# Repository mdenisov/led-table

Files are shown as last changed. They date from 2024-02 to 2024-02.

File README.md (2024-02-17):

Flexible modular system. The modules are connected to each other to form a single network. Each module works independently of the others.

The entire system consists of a basic control module with **ESP8266** and an endless set of sensor modules.

The number of modules is limited only by the power of the power supply.

On the base module you can set the color and brightness of the diodes.

## Build
The hexagon parts always have the same distance to each other, use spacers to insert. Also use hexagon spacers to tightly fill the perimeter

The hexagons are printed in two colors. The top in Black and the rest in Clear.

## PCB
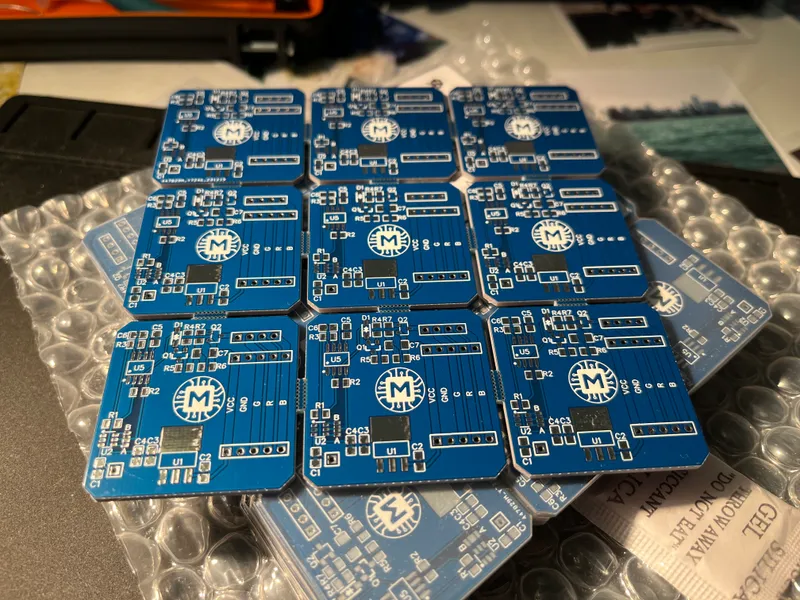
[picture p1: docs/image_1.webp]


Solder pin A for a low signal when sensor triggered. **C1** capacitor serves to reduce the sensitivity of the sensor. I didn't solder it.

You can adjust the glow time and smoothness of the diodes.
All this can be configured on the sensor board by replacing elements **C6**, **R3**, **R5**, **R6**.

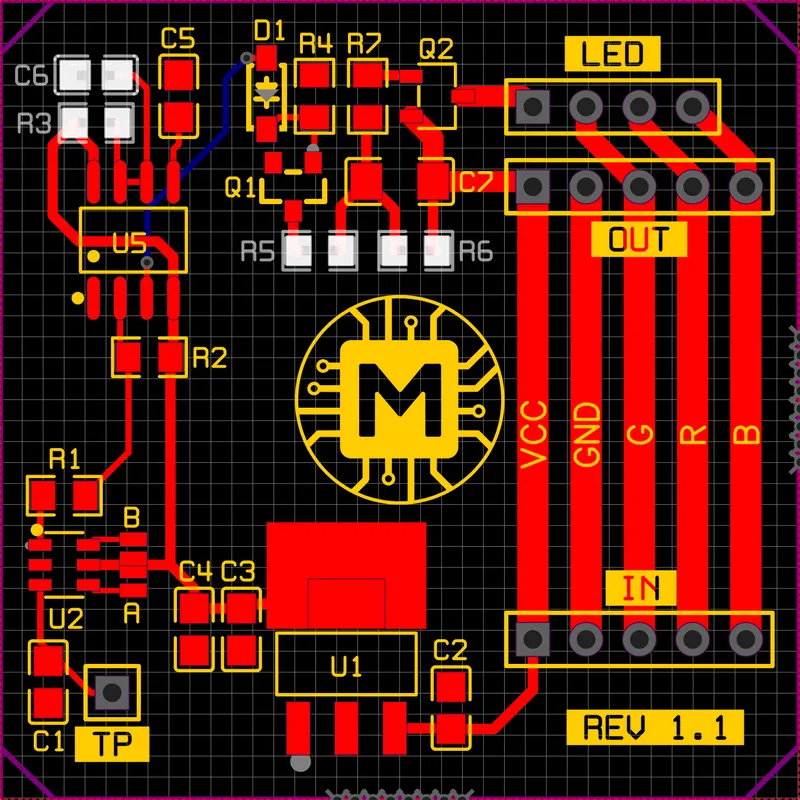
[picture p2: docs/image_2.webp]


- **C6**, **R3** are responsible for the glow time of the diodes and is calculated by the formula t=C6xR3x1.1 (in my case ~1s);
- **R5** is responsible for fade-in of the diodes;
- **R6** is responsible for fade-out of the diodes;

## Assembly
For the sensor to work, it is necessary to make a ring of copper wire, I use 2.5 mm2. For even winding, use a round tower. Solder the ring to the **TP** pin with wire. 

Cut 15cm of LED strip (3 sections) and solder the contacts with wire into a ring. Solder wires to these contacts for further connection to the sensor board.

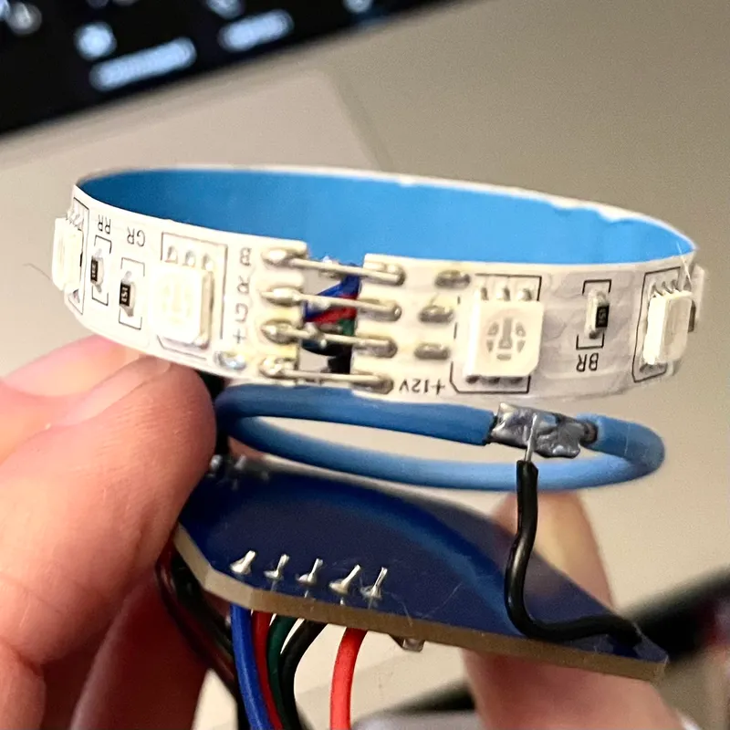
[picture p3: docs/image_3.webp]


You can connect the LED strip both from the inside and from the outside, make sure that the wires are as far away from the touch ring as possible.

Place everything in its place in the hexagon.

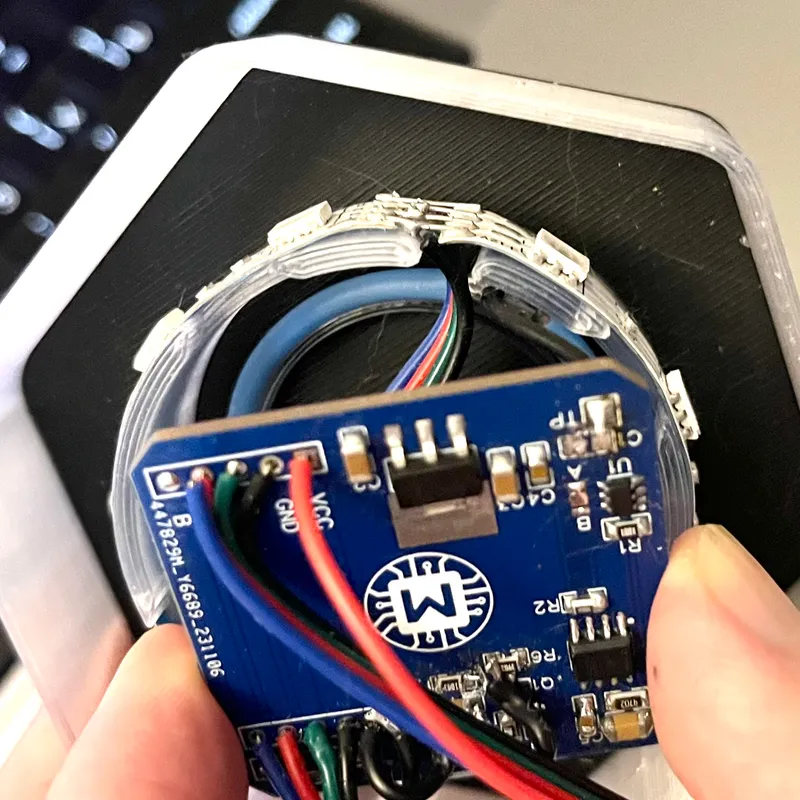
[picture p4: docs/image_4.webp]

pcb
pcb

The sensor module is ready.

The modules are connected sequentially one after another into a single network using JST connectors for quick replacement or hard soldered with wires.

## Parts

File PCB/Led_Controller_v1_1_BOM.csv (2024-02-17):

ID | Name | Designator | Footprint | Quantity | Manufacturer Part | Manufacturer | Supplier | Supplier Part
1 | 10u | C1 | C0805 | 1
2 | 100n | C2,C7 | C0805 | 2
3 | 10n | C3 | C0805 | 1
4 | 3.9n | C4 | C0805 | 1
5 | 22u | C5,C6 | C0805 | 2
6 | 1N4148 | D1,D2,D4 | SOD-123_L2.7-W1.6-LS3.7-RD-1 | 3 | 1N4148 | STMicroelectronics | LCSC | C13769
7 | MBR0530T3G | D3,D5 | SOD-123_L2.7-W1.6-LS3.7-RD-1 | 2 | MBR0530T3G | onsemi(安森美) | LCSC | C236079
8 | HDR-F-2.54_1x5 | H1 | HDR-F-2.54_1X5 | 1 |  |  | LCSC | C50950
9 | 10uH | L1 | IND-SMD_L7.0-W6.6_FXL0630 | 1 | FXL0624-150-M | cjiang(长江微电) | LCSC | C524609
10 | IRLML2502 | Q1,Q2,Q3 | SOT-23_L2.9-W1.3-P1.90-LS2.4-BR | 3 | IRLML2502 | UMW(广东友台半导体) | LCSC | C347503
11 | 10k | R1,R2,R3,R4,R6,R7,R9,R13 | R0805 | 8
12 | 100R | R5,R8,R11 | R0805 | 3
13 | 100k | R10 | R0805 | 1
14 | 47k | R12 | R0805 | 1
15 | 18k | R14 | R0805 | 1
16 | 6.8k | R15 | R0805 | 1
17 | 2.4GHz | U1 | WIFIM-SMD_ESP-12F-ESP8266MOD | 1 | ESP-12F(ESP8266MOD) | Ai-Thinker(安信可) | LCSC | C82891
18 | UART | U2 | UART | 1
19 | VCC | U3 | CONN-TH_P2.54_KF128-2.54-2P | 1 | KF128-2.54-2P | KEFA(科发) | LCSC | C474920
20 | MP2307DN-LF-Z | U4 | SOP-8_L4.9-W3.9-P1.27-LS6.0-BL-EP | 1 | MP2307DN-LF-Z | MPS | LCSC | C18921

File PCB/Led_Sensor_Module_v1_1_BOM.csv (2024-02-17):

ID | Name | Designator | Footprint | Quantity | Manufacturer Part | Manufacturer | Supplier | Supplier Part
1 | 22u | C2,C3,C6 | C0805 | 3
2 | 100n | C4 | C0805 | 1
3 | 10n | C5 | C0805 | 1
4 | 10u | C7 | C1206 | 1
5 | 1N4148 | D1 | SOD-123_L2.7-W1.6-LS3.7-RD-1 | 1 | 1N4148 | STMicroelectronics | LCSC | C13769
6 | HDR-F-2.54_1x5 | H1,H2 | HDR-F-2.54_1X5 | 2 |  |  | LCSC | C50950
7 | LED | H3 | HDR-F-2.54_1X4 | 1 |  |  | LCSC | C225501
8 | TP | J1 | HDR-M-2.54_1X1 | 1 |  |  | LCSC | C81276
9 | IRLML2502 | Q1 | SOT-23_L2.9-W1.3-P1.90-LS2.4-BR | 1 | IRLML2502 | UMW(广东友台半导体) | LCSC | C347503
10 | IRLML2244 | Q2 | SOT-23-3_L2.9-W1.6-P1.90-LS2.8-BR | 1 |  | VBsemi(微碧) | LCSC | C558172
11 | 1k | R1 | R0805 | 1
12 | 10k | R2,R4,R7 | R0805 | 3
13 | 47k | R3 | R0805 | 1
14 | 390k | R5 | R0805 | 1
15 | 100k | R6 | R0805 | 1
16 | AMS1117 | U1 | SOT-223-3_L6.4-W3.5-P2.30-LS7.0-BR | 1 | AMS1117-3.3 | 国芯佳品 | LCSC | C2992570
17 | TTP223-BA6 | U2 | SOT-23-6_L2.9-W1.6-P0.95-LS2.8-BL | 1 | TTP223-BA6 | null | LCSC | C80757
18 | B | U3 | PAD-JUMPER-2-NO_NO_SILK | 1
19 | A | U4 | PAD-JUMPER-2-NO_NO_SILK | 1
20 | NE555 | U5 | SOIC-8_L4.9-W3.9-P1.27-LS6.0-BL | 1 | NE555 | IDCHIP(英锐芯) | LCSC | C5125085

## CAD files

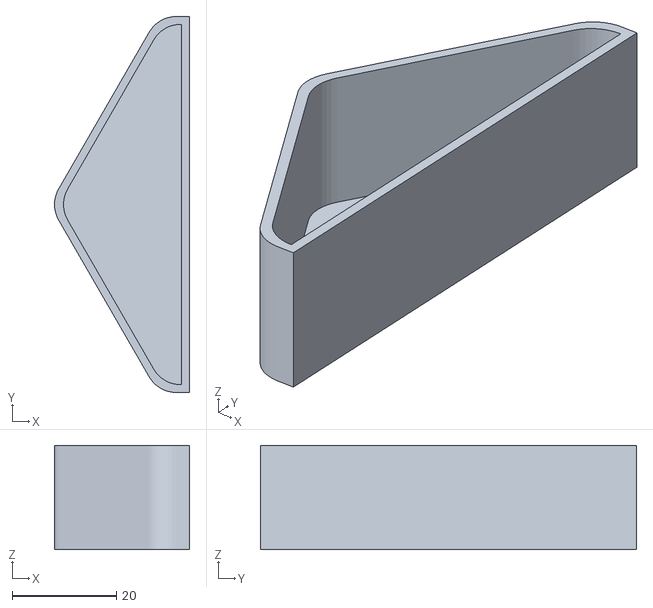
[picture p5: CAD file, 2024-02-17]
STL/Filling_2.stl
25.9 x 72.0 x 20.0

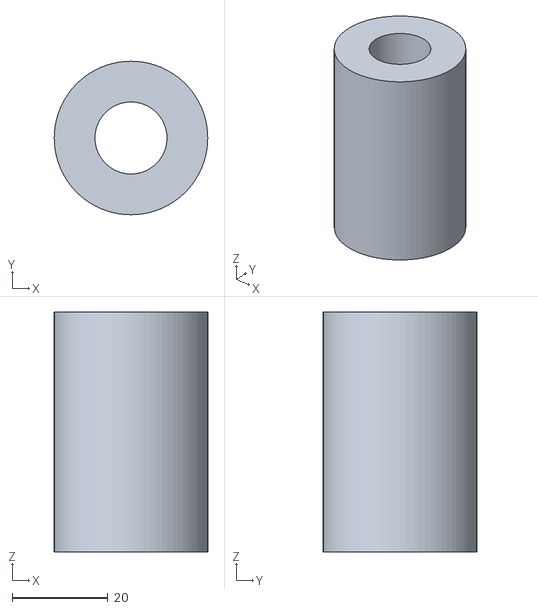
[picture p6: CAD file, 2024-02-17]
STL/Tower.stl
32.0 x 32.0 x 50.0

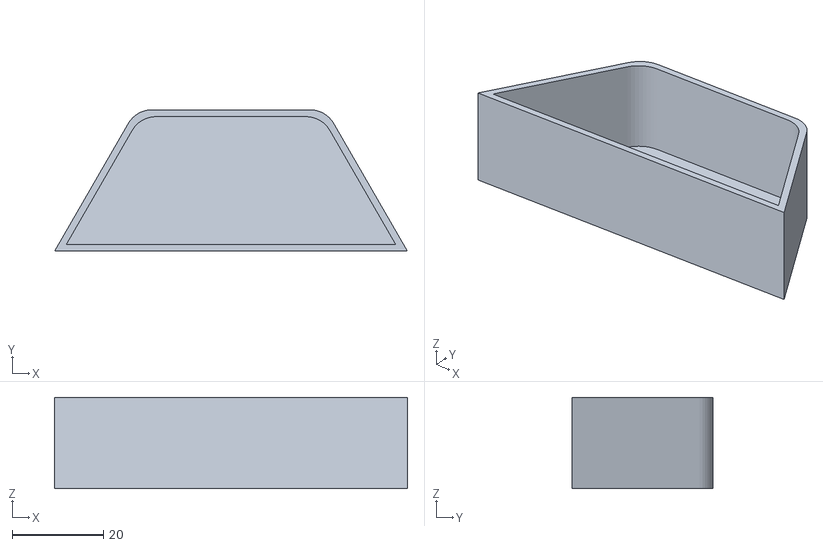
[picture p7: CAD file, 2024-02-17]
STL/Filling_1.stl
77.4 x 31.0 x 20.0

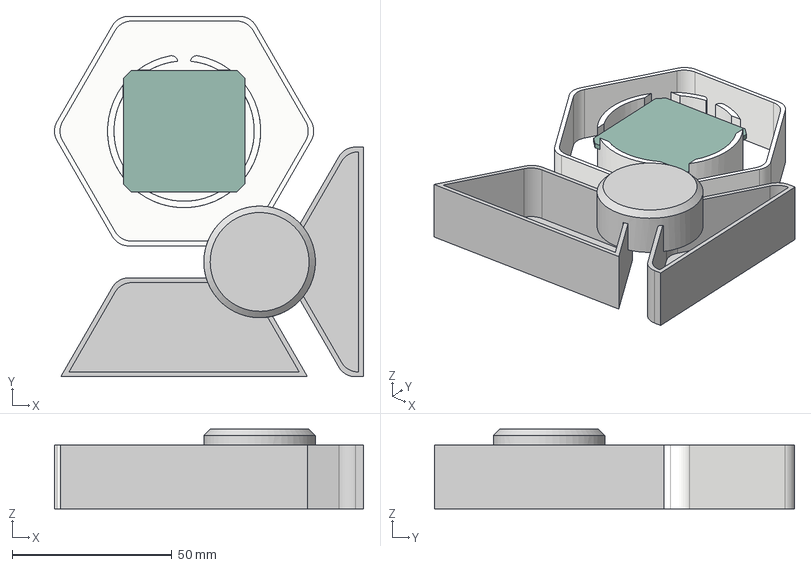
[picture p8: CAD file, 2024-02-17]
STL/Hexagon led table.step
96.9 x 113.0 x 25.0 mm
Base
Filling_1
Filling_2
Spacer
PCB

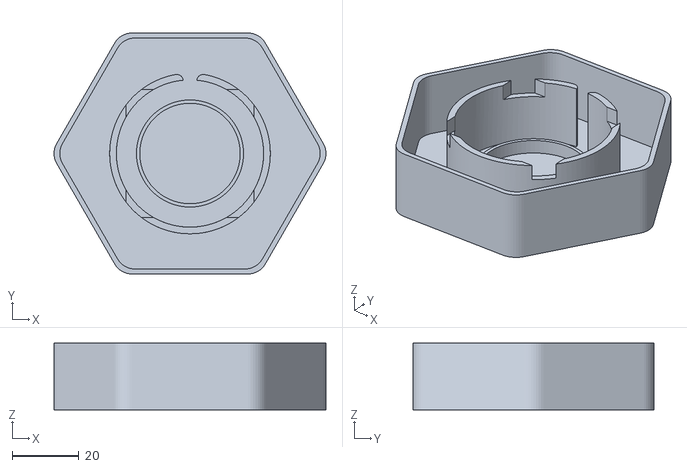
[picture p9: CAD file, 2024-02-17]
STL/Base.stl
81.3 x 72.0 x 20.0

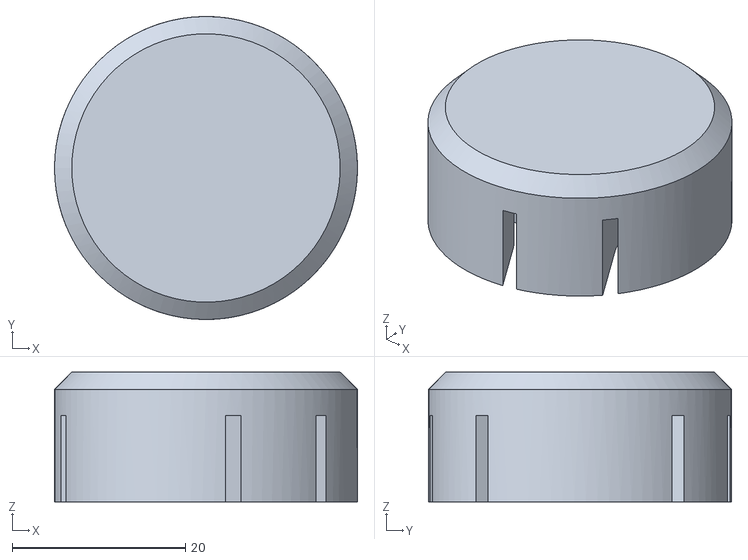
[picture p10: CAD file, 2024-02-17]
STL/Spacer.stl
35.0 x 35.0 x 15.0

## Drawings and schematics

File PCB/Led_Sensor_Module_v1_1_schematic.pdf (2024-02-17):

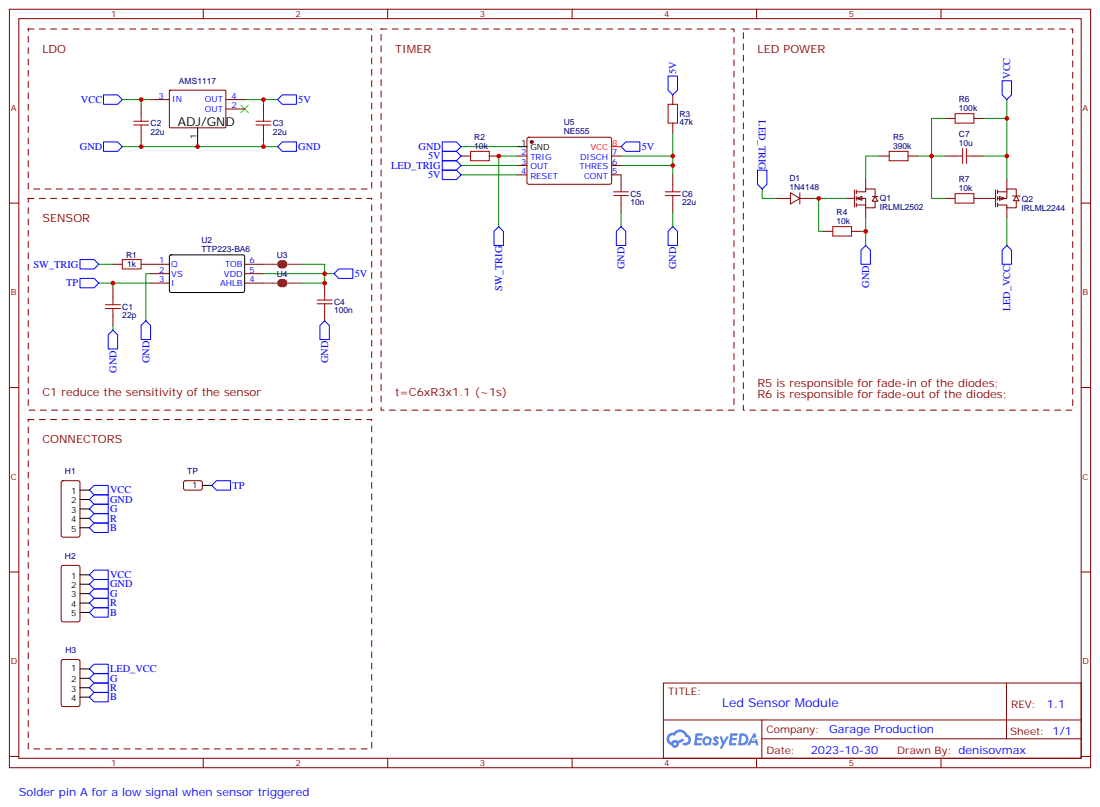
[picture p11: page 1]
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

C1 reduce the sensitivity of the sensor

Solder pin A for a low signal when sensor triggered

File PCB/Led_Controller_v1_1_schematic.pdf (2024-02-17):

## CPU RX - TX

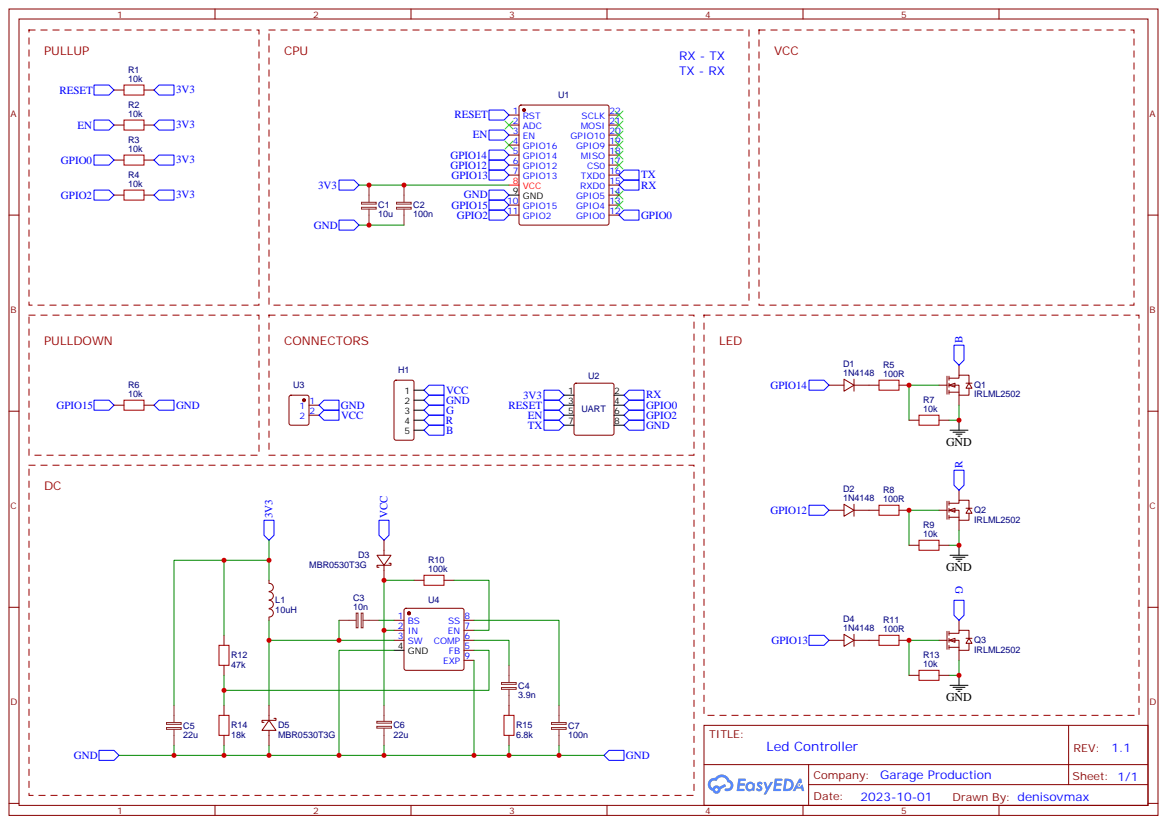
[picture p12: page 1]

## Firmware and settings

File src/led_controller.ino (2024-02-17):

/* ================ Настройки ================ */
#define DEBUG_MODE  // Режим отладки
#define HOSTNAME "Led"
#define PREFIX "Led"
#define AP_DEFAULT_SSID "Wi-Fi Led AP"  // Стандартное имя точки доступа ESP (До 20-ти символов)
#define AP_DEFAULT_PASS "00000000"      // Стандартный пароль точки доступа ESP (До 20-ти символов)
#define STA_DEFAULT_SSID ""             // Стандартное имя точки доступа роутера (До 20-ти символов)
#define STA_DEFAULT_PASS ""             // Стандартный пароль точки доступа роутера (До 20-ти символов)
#define WIFI_TIMEOUT 60000              // Таймаут на подключение к Wi-Fi
#define EE_KEY 0x10                     // Ключ EEPROM (1 байт) - измени, чтобы сбросить настройки
#define VERSION 0.1                     // Версия
/* =========================================== */

/* ================ Распиновка =============== */
#define G_PIN 13
#define R_PIN 12
#define B_PIN 14
/* =========================================== */

/* ============ Список библиотек ============= */
#include <Arduino.h>
#include <EEPROM.h>
#include <GRGB.h>
#include <GyverPortal.h>
#include <LittleFS.h>
/* =========================================== */

/* ============ Список объектов ============== */
GRGB led(COMMON_CATHODE, R_PIN, G_PIN, B_PIN, GRGB_10BIT);
GyverPortal ui(&LittleFS);
WiFiClient wifiClient;
/* =========================================== */

/* ================ Макросы ================== */
#ifdef DEBUG_MODE
#define DEBUG(...) Serial.print(__VA_ARGS__)
#define DEBUGLN(...) Serial.println(__VA_ARGS__)
#else
#define DEBUG(...)
#define DEBUGLN(...)
#endif
/* =========================================== */

/* ========= Глобальные переменные =========== */
// Структура со всеми настройками
struct {
  char apSsid[21] = AP_DEFAULT_SSID;    // Имя сети для AP режима по умолчанию
  char apPass[21] = AP_DEFAULT_PASS;    // Пароль сети для AP режима по умолчанию
  char staSsid[21] = STA_DEFAULT_SSID;  // Имя сети для STA режима по умолчанию
  char staPass[21] = STA_DEFAULT_PASS;  // Пароль сети для STA режима по умолчанию
  bool staModeEn = false;               // Подключаться к роутеру по умолчанию?
  int color = 0xFFFFFF;                 // Цвет
  int brightness = 130;                 // Яркость
} cfg;
bool connectInProgress = false;
bool ledEnabled = false;
/* =========================================== */

/* =============== Колбэки WiFi ============== */
static WiFiEventHandler staConnectedHandler;
static WiFiEventHandler staDisconnectedHandler;
static WiFiEventHandler staGotIPHandler;
static WiFiEventHandler staDHCPTimeoutHandler;
/* =========================================== */

/* ============== Инициализация ============== */
void initPins() {
  DEBUGLN("Init pins");
}

void initEEPROM() {
  DEBUGLN("Init EEPROM");

  // Инициализация EEPROM
  EEPROM.begin(250);
  delay(50);

  // Если ключ еепром не совпадает
  if (EEPROM.read(0) == EE_KEY) {
    // Читаем настройки
    EEPROM.get(1, cfg);
    delay(50);
  } else {
    // Пишем дефолтные настройки
    resetEEPROM();
  }
}

void initUI() {
  // Подключаем билд веб морды
  ui.attachBuild(build);
  // Подключаем обработчик действий
  ui.attach(action);
  // Стартуем!
  ui.start(HOSTNAME);
  // Включаем ОТА для прошивки по воздуху
  ui.enableOTA();
}

void initFS() {
  // Инициализация файловой системы
  LittleFS.begin();
}

void initLed() {
  // led.setCRT(true);
  led.setPower(true);
}

/* ================== Логика ================= */
void updateEEPROM() {
  // Пишем настройки
  EEPROM.put(1, cfg);
  // Запись
  EEPROM.commit();
  delay(50);
}

void resetEEPROM() {
  DEBUGLN("Reset EEPROM");

  // Пишем ключ
  EEPROM.write(0, EE_KEY);
  updateEEPROM();
}

void setColor(uint32_t color, uint8_t br = cfg.brightness) {
  DEBUG("setColor: ");
  DEBUGLN(color, br);
  led.setHEX(color, br);
}

/* =================== WiFi ================== */
void onStaConnected(const WiFiEventStationModeConnected& evt)
{
  connectInProgress = 0;

  DEBUG("WiFi connected: ");
  DEBUG(evt.ssid);
  DEBUG(" ");
  DEBUGLN(evt.channel);
}

void onStaDisconnected(const WiFiEventStationModeDisconnected& evt)
{
  connectInProgress = 1;

  DEBUG("WiFi disconnected: ");
  DEBUG(evt.ssid);
  DEBUG(" ");
  DEBUGLN(evt.reason);
}

void onStaGotIP(const WiFiEventStationModeGotIP& evt)
{
  connectInProgress = 0;

  DEBUG("Got IP: ");
  DEBUG(evt.ip);
  DEBUG(" ");
  DEBUG(evt.mask);
  DEBUG(" ");
  DEBUGLN(evt.gw);
}

void onStaDHCPTimeout()
{
  DEBUGLN("DHCP Timeout");
}

void setupAP() {
  if (WiFi.getMode() == WIFI_AP) {
    return;
  }

  WiFi.persistent(false);
  WiFi.disconnect();
  WiFi.mode(WIFI_AP);
  WiFi.persistent(true);
  WiFi.softAP(cfg.apSsid, cfg.apPass);

  DEBUGLN("Started in AP mode");
  DEBUGLN(WiFi.softAPIP());

  connectInProgress = 0;
}

void setupLocal() {
  if (cfg.staSsid == NULL || cfg.staPass == NULL) {
    DEBUGLN("WiFi not configured");
    setupAP();
  } else {
    DEBUGLN("Connecting WiFi");

    connectInProgress = 1;

    // Включаем wifi
    WiFi.mode(WIFI_STA);
    // WiFi.config(INADDR_NONE, INADDR_NONE, INADDR_NONE, INADDR_NONE);
    // Make sure the wifi does not autoconnect but always reconnects
    WiFi.setAutoConnect(false);
    WiFi.setAutoReconnect(true);

    // WiFi Events
    staConnectedHandler = WiFi.onStationModeConnected(&onStaConnected);
    staDisconnectedHandler = WiFi.onStationModeDisconnected(&onStaDisconnected);
    staGotIPHandler = WiFi.onStationModeGotIP(&onStaGotIP);
    staDHCPTimeoutHandler = WiFi.onStationModeDHCPTimeout(&onStaDHCPTimeout);

    // Задаем сетевое имя
    WiFi.hostname(HOSTNAME);
    // Подключаемся к сети
    WiFi.begin(cfg.staSsid, cfg.staPass, 0, NULL, true);
    delay(2000);
  }
}

void startWiFi() {
  if (cfg.staModeEn) {
    // Подключаемся к роутеру
    setupLocal();
  } else {
    // Режим точки доступа
    setupAP();
  }
}

/* =================== Web =================== */
void build() {           // Билд страницы
  GP.BUILD_BEGIN(400);   // Ширина колонок
  GP.THEME(GP_DARK);     // Темная тема
  GP.PAGE_TITLE("Led");  // Обзываем титл

  if (cfg.staModeEn && WiFi.isConnected()) {
    GP.FORM_BEGIN("/led");    // Начало формы
    GP.GRID_RESPONSIVE(600);  // Отключение респонза при узком экране
    M_BLOCK(                  // Общий блок-колонка для Ленты
      M_BLOCK_TAB("Лента",
                  M_BOX(GP.LABEL("Цвет");
                        GP.COLOR("color", cfg.color););
                  M_BOX(GP.LABEL("Яркость");
                        GP.SLIDER("brightness", cfg.brightness, 0, 255, 1, 0);););
      GP.SUBMIT("Применить");  // Кнопка отправки формы
      GP.FORM_END();           // <- Конец формы (костыль)
    );
  }

  GP.FORM_BEGIN("/cfg");    // Начало формы
  GP.GRID_RESPONSIVE(600);  // Отключение респонза при узком экране
  M_BLOCK(                  // Общий блок-колонка для WiFi
    M_BLOCK_TAB(            // Конфиг для AP режима -> текстбоксы (логин + пароль)
      "AP-Mode",            // Имя + тип DIV
      GP.TEXT("apSsid", "Логин", cfg.apSsid, "", 20);
      GP.BREAK(); GP.PASS_EYE("apPass", "Пароль", cfg.apPass, "", 20);
      GP.BREAK(););
    M_BLOCK_TAB(  // Конфиг для STA режима -> текстбоксы (логин + пароль)
      "WiFi",     // Имя + тип DIV
      GP.TEXT("staSsid", "Логин", cfg.staSsid, "", 20);
      GP.BREAK(); GP.TEXT("staPass", "Пароль", cfg.staPass, "", 20);
      GP.BREAK(); M_BOX(GP_CENTER, GP.LABEL("WiFi Enable");
                        GP.SWITCH("staEn", cfg.staModeEn);););
    GP.SUBMIT("Сохранить");  // Кнопка отправки формы
    GP.FORM_END();           // <- Конец формы (костыль)

    M_BLOCK_TAB(          // Блок с OTA-апдейтом
      "ESP UPDATE",       // Имя + тип DIV
      GP.OTA_FIRMWARE();  // Кнопка с OTA начинкой
    ););
  GP.BUILD_END();  // Конец билда страницы
}

// Подсос значений со страницы
void action(GyverPortal &p) {
  // Если есть сабмит формы - копируем все в переменные
  if (p.form("/led")) {
    DEBUGLN("Led form");

    p.copyInt("color", cfg.color);
    p.copyInt("brightness", cfg.brightness);

    // Сохраняем все настройки в EEPROM
    updateEEPROM();
    delay(50);
    setColor(cfg.color, cfg.brightness);
  }

  if (p.form("/cfg")) {
    DEBUGLN("Cfg form");

    p.copyStr("apSsid", cfg.apSsid);
    p.copyStr("apPass", cfg.apPass);
    p.copyStr("staSsid", cfg.staSsid);
    p.copyStr("staPass", cfg.staPass);
    p.copyBool("staEn", cfg.staModeEn);

    // Сохраняем все настройки в EEPROM
    updateEEPROM();

    // Перегружаем ESP
    ESP.restart();
  }
}

/* ============= Главные функции ============= */
void setup() {
#ifdef DEBUG_MODE
  Serial.begin(115200);
#endif

  initPins();
  initEEPROM();
  startWiFi();
  initLed();
  initUI();
  initFS();
}

void loop() {
  ui.tick();

  // Если долго нет подключения, запускаем AP
  static uint32_t wifiConnectingTmr = millis();
  if (cfg.staModeEn && !WiFi.isConnected()) {
    if (millis() - wifiConnectingTmr > 5 * 60 * 1000) {
      wifiConnectingTmr = millis();
      setupAP();
    }
  }
}
